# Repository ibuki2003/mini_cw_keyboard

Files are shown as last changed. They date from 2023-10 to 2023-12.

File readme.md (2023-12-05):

# モールスキーボード

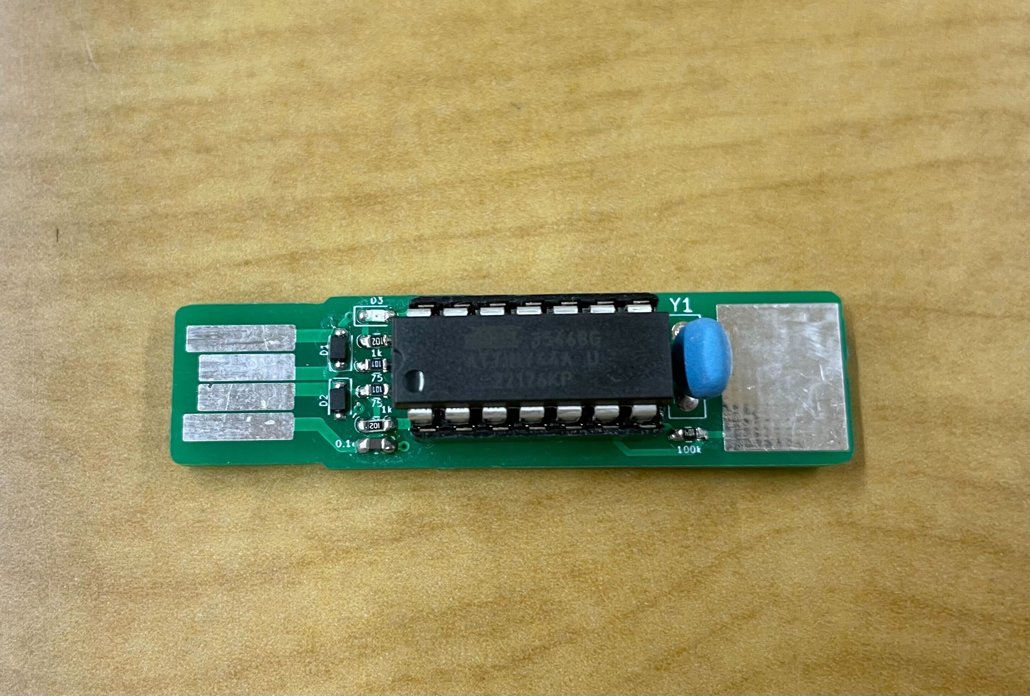
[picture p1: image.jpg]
完成品の写真


## 使い方

モールス信号でPCに文字を入力することができる、小型のキーボードです。
お使いのPCのUSB端子に接続し、タッチパッド（銀色の部分）を使ってモールス信号を入力すると、対応するキーが入力されます。

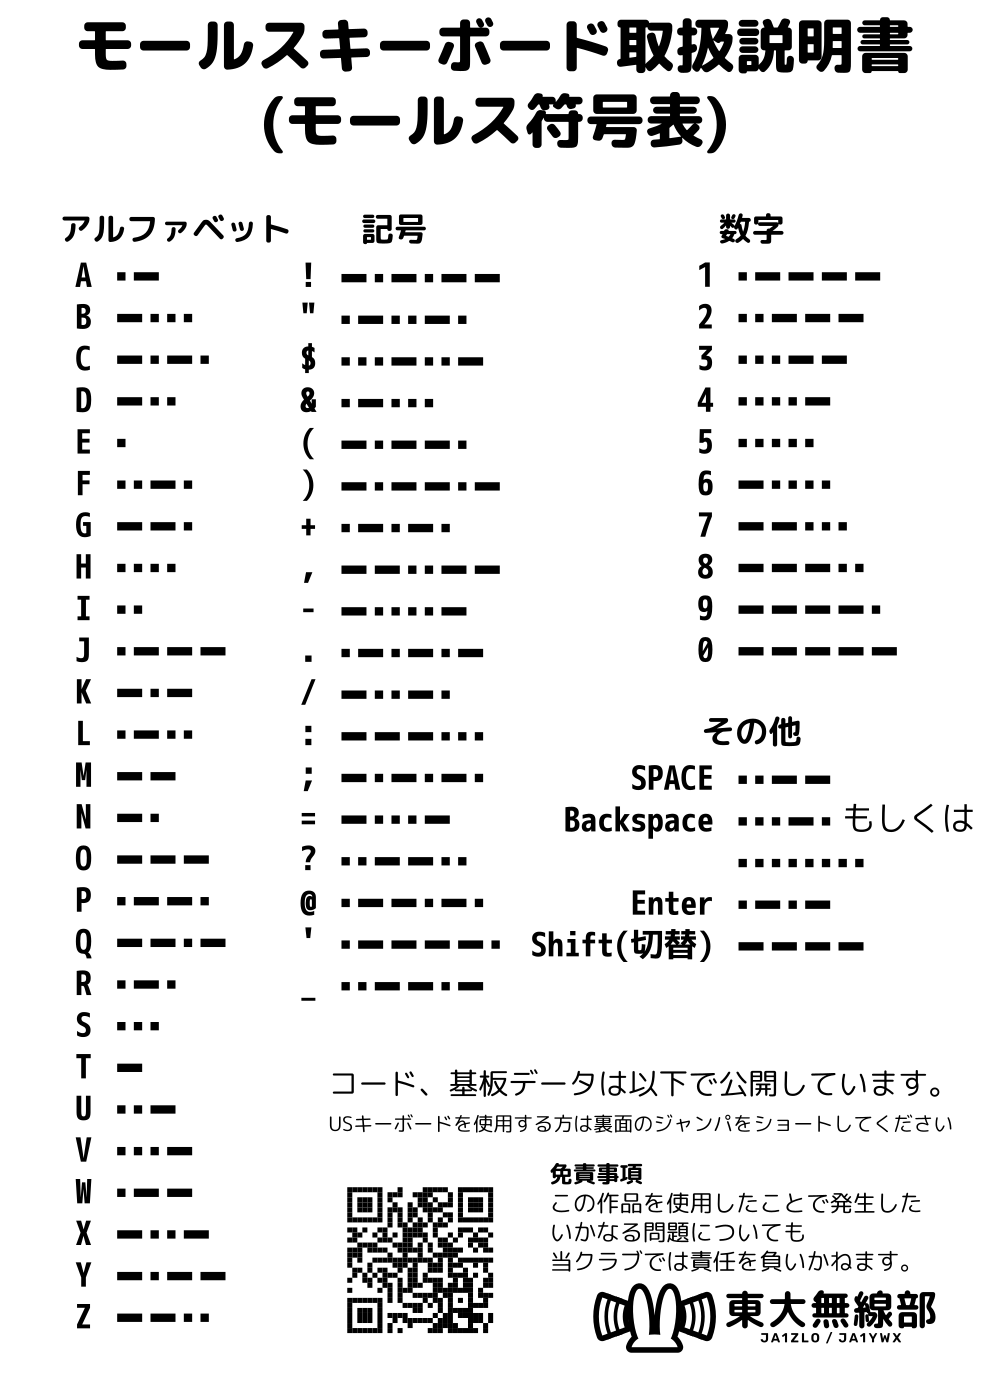
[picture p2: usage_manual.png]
取扱説明書 (モールス符号表)


## GitHubリポジトリについて

### board

回路図、基板レイアウトがKiCAD形式で置かれています。
KiCADはオープンソースソフトウェアであり、Windows, Mac, Linux版等が入手可能です。

### program

マイコンに書き込んだプログラムのソースコードが置かれています。

## License

The program depends on the following libraries:

- V-USB
    - https://www.obdev.at/vusb/

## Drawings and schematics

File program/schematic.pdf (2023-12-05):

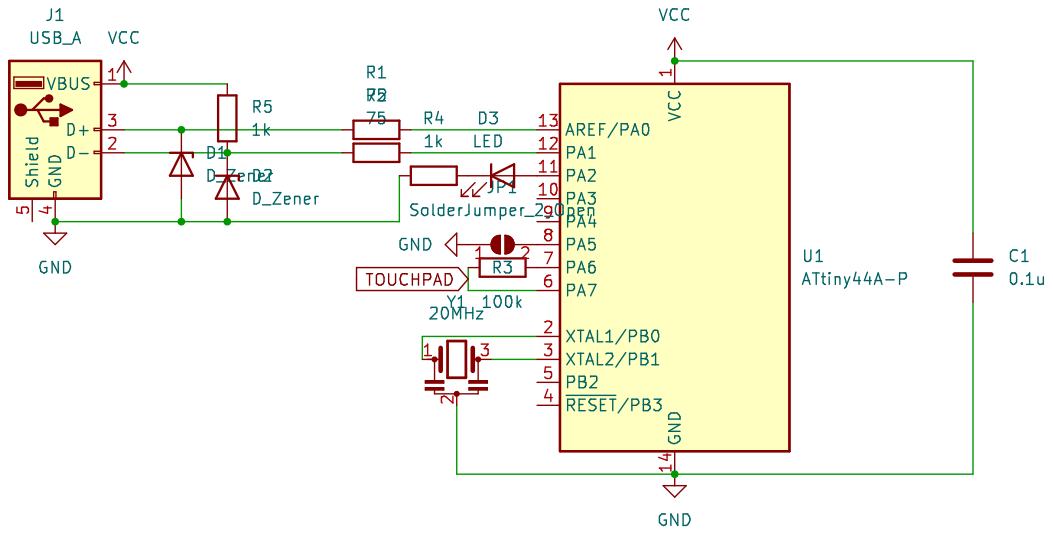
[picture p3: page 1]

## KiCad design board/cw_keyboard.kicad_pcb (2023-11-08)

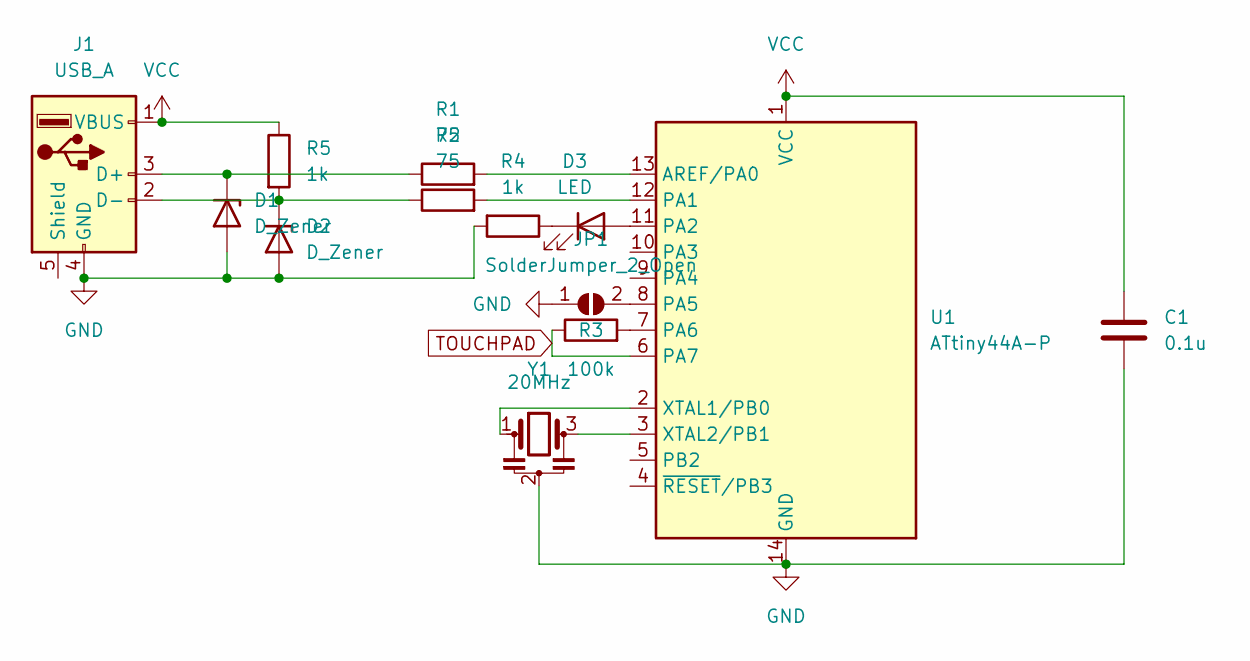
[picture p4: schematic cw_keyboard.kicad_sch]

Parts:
C1: 0.1u; C_0603_1608Metric_Pad1.08x0.95mm_HandSolder
D1, D2: D_Zener; D_UMD2
D3: LED; LED_0603_1608Metric_Pad1.05x0.95mm_HandSolder
J1: USB_A; USB-A_Connector_Direct
JP1: SolderJumper_2_Open; SolderJumper-2_P1.3mm_Open_RoundedPad1.0x1.5mm
R1, R2: 75; R_0603_1608Metric_Pad0.98x0.95mm_HandSolder
R3: 100k; R_0603_1608Metric_Pad0.98x0.95mm_HandSolder
R4, R5: 1k; R_0603_1608Metric_Pad0.98x0.95mm_HandSolder
U1: ATtiny44A-P; DIP-14_W7.62mm
Y1: 20MHz; PinHeader_1x03_P2.54mm_Vertical

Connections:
GND: C1.2, D1.2 (A), D2.2 (A), J1.4 (GND), JP1.1 (A), R4.2, U1.14 (GND), Y1.2
unnamed: D1.1 (K), J1.3 (D+), R1.1
unnamed: D2.1 (K), J1.2 (D-), R2.1, R5.2
unnamed: D3.2 (A), U1.11 (PA2)
unnamed: D3.1 (K), R4.1
unnamed: JP1.2 (B), U1.8 (PA5)
unnamed: R1.2, U1.13 (AREF/PA0)
unnamed: R2.2, U1.12 (PA1)
unnamed: R3.2, U1.7 (PA6)
unnamed: U1.2 (XTAL1/PB0), Y1.1
unnamed: U1.3 (XTAL2/PB1), Y1.3
TOUCHPAD: R3.1, U1.6 (PA7)
VCC: C1.1, J1.1 (VBUS), R5.1, U1.1 (VCC)

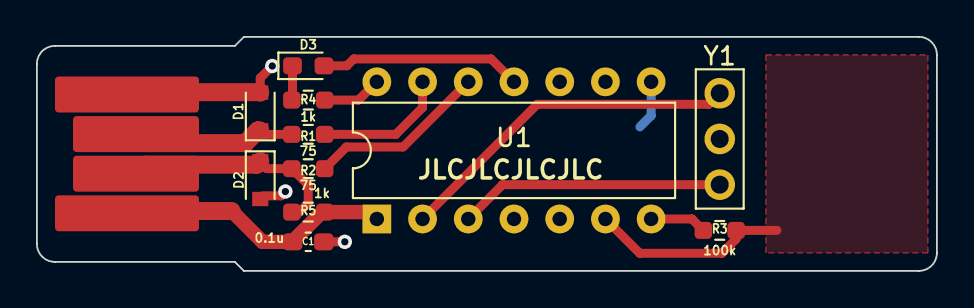
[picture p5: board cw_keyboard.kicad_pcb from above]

Board: 2 copper layers, 50.0 x 13.0 mm, 13 parts (1 on the bottom side), 13 nets.

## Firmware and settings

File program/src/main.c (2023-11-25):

#include "avr/interrupt.h"
#include "util/delay.h"
#include <avr/io.h>
#include <avr/wdt.h>
#include <usbdrv.h>
#include <stdbool.h>

#include "morse.h"

#define LED_PIN 2
#define BTN_PIN 3
#define JMP_PIN 5 // jumper to select keyboard layout; GND for US, open for JIS
#define TOUCH_IN_PIN 7
#define TOUCH_OUT_PIN 6

#define BIT(x) (1 << (x))

#define TCNT1H_ ((uint8_t)(TCNT1 >> 8))

#define TOUCH_THRES 9

#define DASH_THRES 0x30 // 0x30 * 256 / (20M / 256) ~ 150 ms
#define BLANK_THRES 0x50

uint8_t reportBuffer[2];

int main() {
  // setup
  DDRA = BIT(LED_PIN) | BIT(TOUCH_OUT_PIN);
  PORTA = BIT(JMP_PIN); // pull-up for input pin
  // MCUCR &= ~BIT(PUD); // allowed by default

  TCCR1A = 0;
  TCCR1B = (0b100 << CS10); // 256 prescaler

  usbInit();
  usbDeviceConnect();
  sei();

  // key to send at next interrupt
  uint8_t k = 0;
  bool shift = 0;

  uint8_t h = 0; // hysteresis
  bool v = 0; // current btn state
  bool v_last = 0; // last btn state

  uint8_t t = 0; // timer state

  /**
    the value represents the morse code input

    empty: 0
    dot: v = v * 2 + 1
    dash: v = v * 2 + 2

    this enables us to use a single byte to represent the morse code input
    */
  uint8_t morse_value = 0;
  uint8_t morse_len = 0;

  uint8_t pulser_cnt = 0;

  while (1) {
    wdt_reset();
    usbPoll();

    const bool layout_jis = PINA & BIT(JMP_PIN); // read jumper

    if (k && usbInterruptIsReady()) {
      if (k == 0xff) k = 0;
      if (k == 0x87 && layout_jis) {
        // this is a hack to send '_' on JIS layout
        // keycode of '_' is greater than 0x7f
        reportBuffer[0] = 0b10;
        reportBuffer[1] = 0x87;
      } else {
        reportBuffer[0] = (k & BIT(7)) >> 6; // Left Shift key
        reportBuffer[1] = k & 0x7f; // msb for shift key
      }
      usbSetInterrupt(reportBuffer, sizeof(reportBuffer));
      k = k ? 0xff : 0; // release
    }


    // touch sensor
    // check every 16th time
    ++pulser_cnt; pulser_cnt &= 0x0f;
    if (pulser_cnt == 0) {
      if (!(PORTA & BIT(TOUCH_OUT_PIN))) {
        uint8_t rise_time_cnt = 1;
        PORTA |= BIT(TOUCH_OUT_PIN);
        while (rise_time_cnt <= TOUCH_THRES && !(PINA & BIT(TOUCH_IN_PIN))) {
          ++rise_time_cnt;
        }
        rise_time_cnt = rise_time_cnt > TOUCH_THRES;

        // hyseteresis
        if (v != rise_time_cnt) {
          ++h;
          if (h > 20) {
            h = 0;
            v = rise_time_cnt;
          }
        } else {
          h = 0;
        }

      } else {
        PORTA &= ~BIT(TOUCH_OUT_PIN);
      }
    }

    if (v) PORTA |= BIT(LED_PIN);
    else PORTA &= ~BIT(LED_PIN);

    if (t == 0 && TCNT1H_ > (v_last ? DASH_THRES : BLANK_THRES)) {
      t = 1;
      if (v_last == 0) {
        if (morse_value == 30) {// shift key: ----
          shift = !shift;
        } else {
          // commit char
          k = morse_to_key(
            morse_value,
            morse_len,
            layout_jis
          );
          if (shift && k && k <= 0x1D) {
            k |= BIT(7);
          }
        }
        morse_value = 0;
        morse_len = 0;
      }
    }

    if (v != v_last) {
      v_last = v;
      if (v == 0) {
        // falling edge
        if (t == 1) {
          // dash
          morse_value = morse_value * 2 + 2;
        } else {
          // dot
          morse_value = morse_value * 2 + 1;
        }
        ++morse_len;
      }
      TCNT1 = 0;
      t = 0;
    }
  }
}

static uchar idleRate = 0;

usbMsgLen_t usbFunctionSetup(uchar data[8]) {
  usbRequest_t *rq = (void *)data;

  if((rq->bmRequestType & USBRQ_TYPE_MASK) == USBRQ_TYPE_CLASS) {
    switch(rq->bRequest) {
      case USBRQ_HID_GET_REPORT:
        usbMsgPtr = reportBuffer;
        return sizeof(reportBuffer);
      case USBRQ_HID_GET_IDLE:
        usbMsgPtr = &idleRate;
        return 1;
      case USBRQ_HID_SET_IDLE:
        idleRate = rq->wValue.bytes[1];
    }
  }
  return 0;
}

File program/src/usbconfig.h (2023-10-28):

#include <avr/io.h>
/* Name: usbconfig.h
 * Project: V-USB, virtual USB port for Atmel's(r) AVR(r) microcontrollers
 * Author: Christian Starkjohann
 * Creation Date: 2005-04-01
 * Tabsize: 4
 * Copyright: (c) 2005 by OBJECTIVE DEVELOPMENT Software GmbH
 * License: GNU GPL v2 (see License.txt), GNU GPL v3 or proprietary (CommercialLicense.txt)
 */

#ifndef __usbconfig_h_included__
#define __usbconfig_h_included__

/*
General Description:
This file is an example configuration (with inline documentation) for the USB
driver. It configures V-USB for USB D+ connected to Port D bit 2 (which is
also hardware interrupt 0 on many devices) and USB D- to Port D bit 4. You may
wire the lines to any other port, as long as D+ is also wired to INT0 (or any
other hardware interrupt, as long as it is the highest level interrupt, see
section at the end of this file).
+ To create your own usbconfig.h file, copy this file to your project's
+ firmware source directory) and rename it to "usbconfig.h".
+ Then edit it accordingly.
*/

/* ---------------------------- Hardware Config ---------------------------- */

#define USB_CFG_IOPORTNAME      A
/* This is the port where the USB bus is connected. When you configure it to
 * "B", the registers PORTB, PINB and DDRB will be used.
 */
#define USB_CFG_DMINUS_BIT      1
/* This is the bit number in USB_CFG_IOPORT where the USB D- line is connected.
 * This may be any bit in the port.
 */
#define USB_CFG_DPLUS_BIT       0
/* This is the bit number in USB_CFG_IOPORT where the USB D+ line is connected.
 * This may be any bit in the port. Please note that D+ must also be connected
 * to interrupt pin INT0! [You can also use other interrupts, see section
 * "Optional MCU Description" below, or you can connect D- to the interrupt, as
 * it is required if you use the USB_COUNT_SOF feature. If you use D- for the
 * interrupt, the USB interrupt will also be triggered at Start-Of-Frame
 * markers every millisecond.]
 */
#define USB_CFG_CLOCK_KHZ       (F_CPU/1000)
/* Clock rate of the AVR in kHz. Legal values are 12000, 12800, 15000, 16000,
 * 16500, 18000 and 20000. The 12.8 MHz and 16.5 MHz versions of the code
 * require no crystal, they tolerate +/- 1% deviation from the nominal
 * frequency. All other rates require a precision of 2000 ppm and thus a
 * crystal!
 * Since F_CPU should be defined to your actual clock rate anyway, you should
 * not need to modify this setting.
 */
#define USB_CFG_CHECK_CRC       0
/* Define this to 1 if you want that the driver checks integrity of incoming
 * data packets (CRC checks). CRC checks cost quite a bit of code size and are
 * currently only available for 18 MHz crystal clock. You must choose
 * USB_CFG_CLOCK_KHZ = 18000 if you enable this option.
 */

/* ----------------------- Optional Hardware Config ------------------------ */

/* #define USB_CFG_PULLUP_IOPORTNAME   D */
/* If you connect the 1.5k pullup resistor from D- to a port pin instead of
 * V+, you can connect and disconnect the device from firmware by calling
 * the macros usbDeviceConnect() and usbDeviceDisconnect() (see usbdrv.h).
 * This constant defines the port on which the pullup resistor is connected.
 */
/* #define USB_CFG_PULLUP_BIT          4 */
/* This constant defines the bit number in USB_CFG_PULLUP_IOPORT (defined
 * above) where the 1.5k pullup resistor is connected. See description
 * above for details.
 */

/* --------------------------- Functional Range ---------------------------- */
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

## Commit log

2023-10-26 feat: implement touch sensor
2023-10-28 feat: add pcb design files
    [cw_keyboard-B_Cu.gbr, cw_keyboard-B_Mask.gbr, cw_keyboard-B_Silkscreen.gbr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]
2023-11-07 fix: correct pin number
    [main.c]
2023-11-07 feat: add bypass capacitor
    [cw_keyboard.kicad_pcb, cw_keyboard.kicad_sch]
2023-11-07 chore: ignore out file
    [cw_keyboard-B_Cu.gbr, cw_keyboard-B_Mask.gbr, cw_keyboard-B_Silkscreen.gbr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]
2023-11-08 feat: add jumper to switch US/JIS layout
    [cw_keyboard.kicad_pcb, cw_keyboard.kicad_sch]
2023-11-08 fix: twist pair distance
    [cw_keyboard.kicad_pcb]
2023-11-19 feat: switch key layout dynamically
2023-11-20 fix: fusebit comment was wrong
2023-11-25 fix: update keycode for jis layout
    [main.c]
